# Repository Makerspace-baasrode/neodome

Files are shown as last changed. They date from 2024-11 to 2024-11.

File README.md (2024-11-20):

# Neodome
Neodome is geodesic dome made from PVC tube trusses lined with neopixel LED strips. Its first installation was in August 16th to 18th 2024 at [Fri3d Camp](https://fri3d.be/), a hacker camp in Belgium.

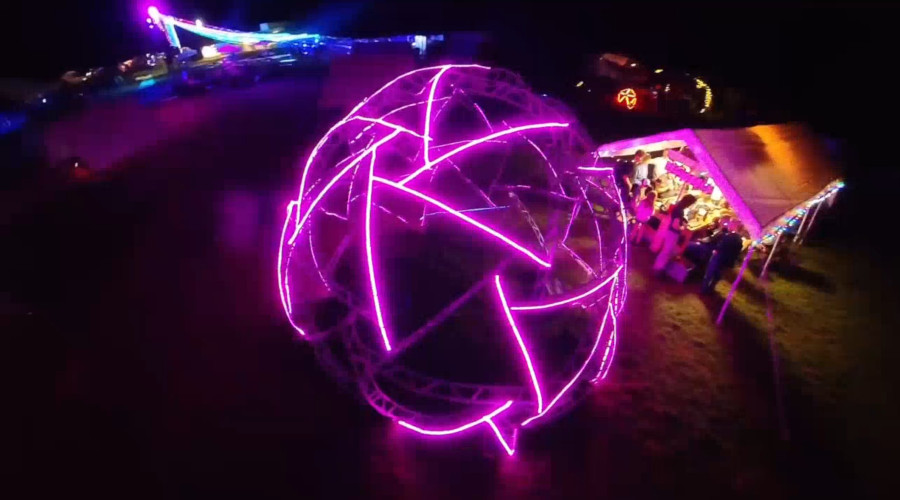
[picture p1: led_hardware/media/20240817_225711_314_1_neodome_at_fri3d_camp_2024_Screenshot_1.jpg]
Neodome at Fri3d Camp 2024


## Neo Dome? Neodome!
[Koen](https://github.com/kavers1) explains that the project is called "Neodome" for these reasons:
1. It features a *dome* with *neo*pixels.
2. It represents a *new* design of a geodesic dome, specifically for Koen.
3. The design, as far as he has been able to find, appears to be *unique*. The shape incorporates pentagons and hexagons, with triangles in between, a configuration that Koen has not yet come across on any other websites or in his searches. While he hasn't conducted an exhaustive search, he has already explored numerous resources. Hence, he chose the name **Neodome**.

## Folders
This project is divided in these folders:
- [dome_hardware](./dome_hardware/): The geodesic dome hardware (constructed with PVC electrical conduits).
- [led_hardware](./led_hardware/): The LED hardware (power supplies, addressable LED strips, power distribution and IRA nodes).
- [led_software](./led_software/): firmware running on the IRA nodes (WLED, WLED with NATS) and possibly other external software controlling the lighting.

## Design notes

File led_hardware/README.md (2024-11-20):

# Neodome lighting hardware and network infrastructure setup

Neodome uses 15 **IRA boards** that each control 5 addressable LED strips. The [IRA](https://github.com/phyx-be/IRA) is a printed circuit board with an ESP32 to control LEDs (or other lighting equipment). The PCB is designed for a 5 or 12V DC supply voltage and has outputs for WS2812-style adressable LEDs and optional DMX. Because of the size of neodome, 12V power is used.

An **IRA node** is an electrical juncion box housing an IRA PCB (to make it somewhat wheater proof). The node has a black/red wire pair for the 12V DC supply and 5 wire triplets with wheather proof connectors for connecting an LED strip. Every box is marked with the node number (926-930) on the front and back. An IRA node is mounted in the intersection of 6 trusses on the *neodome* and feeds the LED strips of 5 trusses. The LED strip of the 'missing' truss is fed by an adjacent IRA node.

By default IRA runs Micropython and NATS is used to transfer commands over wifi. For neodome the IRA boards are flashed with standard WLED firmware. Future plan is flashing WLED with the IRA_NATS usermod: https://github.com/kavers1/WLED/tree/NATS-IO

## Bill Of Materials
* LED strips: type, lengths?
* 15 IRA nodes
* 230V AC to 12V DC power supplies
* 12V DC distribution cables: lenght?
* Lots of WAGO connectors for connecting the power supplies to the distribution cables and the distribution cables to the IRA bnodes
* Wifi AP 

## Wifi
The Wifi AP is an Aruba AP-105 access point running OpenWRT. It is configured to run standalone on PoE without an ethernet uplink and supplies reserved IP-addresses to the IRA nodes.

## WLED on IRA

### Network Parameters

| IRA Node name | IP address | ESP wifi MAC |
|---|---|---|
| wled-Dome-Node-916 | 10.5.5.16  | C8:2B:96:8A:54:1C |
| wled-Dome-Node-917 | 10.5.5.17  | C8:2B:96:8B:15:98 |
| wled-Dome-Node-918 | 10.5.5.18  | C8:2B:96:8B:16:F4 |
| wled-Dome-Node-919 | 10.5.5.19  | C8:2B:96:8B:17:10 |
| wled-Dome-Node-920 | 10.5.5.20  | C8:2B:96:8B:17:64 |
| wled-Dome-Node-921 | 10.5.5.21  | C8:2B:96:8B:17:94 |
| wled-Dome-Node-922 | 10.5.5.22  | C8:2B:96:8B:16:D4 |
| wled-Dome-Node-923 | 10.5.5.23  | C8:2B:96:8B:16:C4 |
| wled-Dome-Node-924 | 10.5.5.24  | C8:2B:96:8B:16:D8 |
| wled-Dome-Node-925 | 10.5.5.25  | C8:2B:96:8B:15:88 |
| wled-Dome-Node-926 | 10.5.5.26  | C8:2B:96:8B:16:D0 |
| wled-Dome-Node-927 | 10.5.5.27  | C8:2B:96:8B:17:5C |
| wled-Dome-Node-928 | 10.5.5.28  | C8:2B:96:8B:15:94 |
| wled-Dome-Node-929 | 10.5.5.29  | C8:2B:96:8B:16:F8 |
| wled-Dome-Node-930 | 10.5.5.30  | C8:2B:96:8B:17:14 |

The DHCP configuration of the wifi access point has IP reservations mapping the MAC to the assigned IP address for every IRA node.

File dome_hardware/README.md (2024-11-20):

# Neodome
Neodome is a neopixel lined geodesic dome. This README covers the build of the geodesic dome.

First build of the neodome, banaan for scale

## Bill Of Materials
- PVC electrical conduit tubes
  - 20x big: diameter? length?
  - 100x? small: diameter? length?
- PVC glue
- 260 to 280 [Locking Pin](https://www.techniekwebshop.nl/gopart-borgpen-8-x-45mm-lp845gp-45-mm-7-mm.html)

## Tools
<!-- TO DO: add the needed tools for component build and assembly -->
- 8.5mm drill for Locking Pin holes

## Component build
Build the appropriate amount of every component.

| Component | Amount needed | STL file for 3D printing a model |
|---|---:|---|
| Penta truss | 40 | [model/penta_truss3_3D.stl] |
| Hexa truss | 20 | [model/hexa_truss3_3D.stl] |
| Penta ground truss | 5 | [model/penta_ground_truss3_3D.stl] |
| Hexa ground truss | 5 | [model/hexa_ground_truss3_3D.stl] |
| Ground truss | 5 | [model/hexa_ground_truss3_3D.stl] |

### Printing a 3D model
The [model](model/) folder contains STL files you can print with a 3D printer. If you first build the dome with the 3D printed pieces, you have a model as reference. If you use a scaling factor of 0.1, 1 m becomes 10 cm.

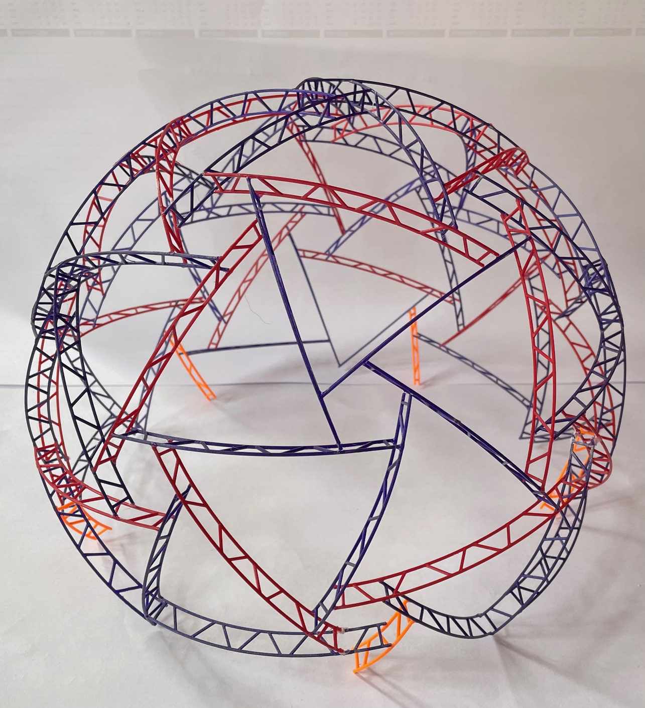
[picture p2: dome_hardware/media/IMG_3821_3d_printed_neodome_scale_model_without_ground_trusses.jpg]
A 3D printed scale model of neodome without the ground trusses


If you also print the *ground trusses*, your model will stand more stable:
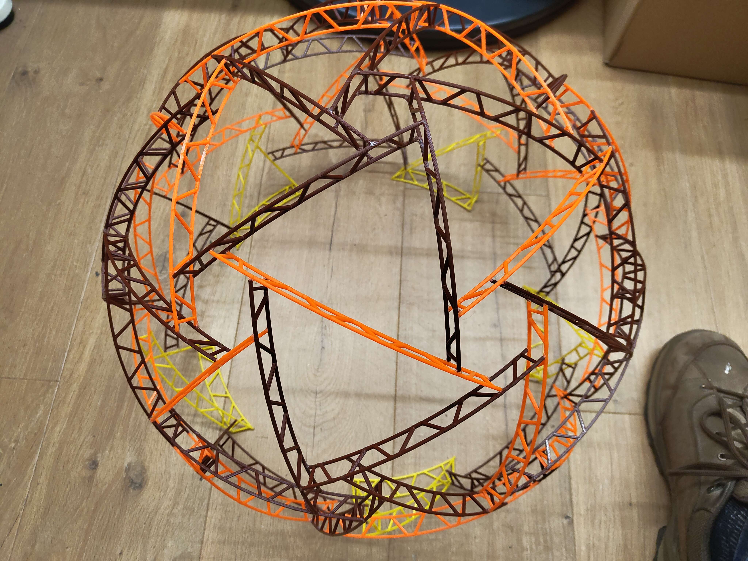
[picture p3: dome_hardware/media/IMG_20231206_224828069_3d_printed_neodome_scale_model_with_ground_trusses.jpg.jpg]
A 3D printed scale model of neodome with the ground trusses


### Tube lengths

- 500x Diagonals of ? length and ? diameter
- **To be further determined**

### Tube hole drilling

You can use a jig for drilling the holes at the correct spacing:
A simple but effective hole drilling jig

### Truss construction

You will need different diameters and lengths of PVC electrical conduit to build every component. Every truss component is a 2D construction consisting of 2 long tubes connected by short diagonals and 2 shorter connecting tubes at each end that accept another truss:

A completed truss
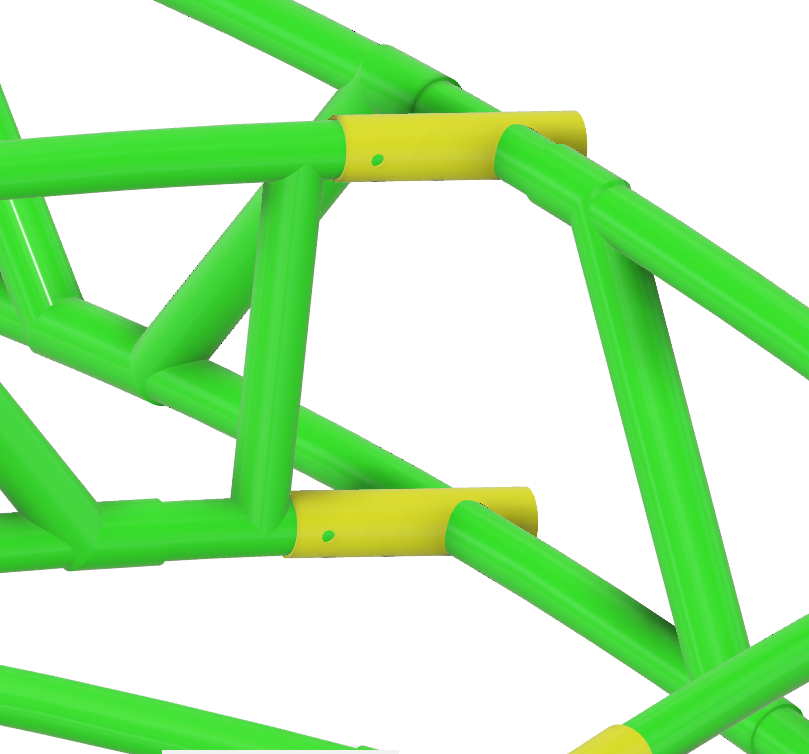
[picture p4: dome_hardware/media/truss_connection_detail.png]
3D generated detail of a truss connector (yellow)


| Component | Outer Diameter | Length | Amount |
|---|---|---|---|

## Component Assembly
Assemble the components is the correct steps. First building the top part.

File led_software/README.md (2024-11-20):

# WLED software

To keep it simple, and as a first step to light up the neodome, we use the default WLED firmware.

## WLED configuration files

To simplify the WLED configuration for 15 nodes, open the [WLED configuration template](wled_cfg_neodome_NNN.json) and find and replace NNN with the IRA Node number. Save the resulting file as wled_cfg_neodome_-`Node number`.json

## Flashing WLED firmware on IRA board

1.  Disconnect everything from the IRA board: no LED strips or 12V power!
2.  Push the BOOT button on the PCB while connecting the PCB with USB-C to your PC.
3.  Open the [WLED web installer](https://install.wled.me) in a chromium-based web browser.
4.  Select firmware version 0.14.3 build 2404040
> Note that we experienced serious lag and irresponsiveness running WLED firmware version 0.14.4! This was manifested in mostly timeouts and occasional high ping responses exceeding 1 second while normal responses should be around 10 milliseconds or less. 
5.  Click `Install` and select the appropriate serial port and Connect.
6.  Click `INSTALL WLED` and `INSTALL`. This will take about 2 minutes.
7.  Click `NEXT` when installation is complete, select the `Makerspace-Baasrode` wifi network and enter the Password to connect.
8.  Click `VISIT DEVICE` to open the WLED web interface

## WLED on IRA configuration

1.  Navigate to the WLED web interface of the neodome IRA board
2.  Config > Security & Updates
3.  Choose file under `Restore presets`, select `wled_presets_neodome.json` and click `Upload`. You should get a green `File Uploaded!` popup.
4.  Choose file under `Restore configuration`, select wled_cfg_neodome_`Node number`.json and click `Upload`. You should get a green `Configuration restores succesfull. Rebooting!` popup.

## WLED on IRA manual configuration via GUI
        
- Wifi setup
  - Network name: `Makerspace-Baasrode`
  - Network password: `password`
  - mDNS address: `wled-930`
  - AP SSID: `WLED-AP-930`
- LED Preferences
  - Maximum Current: `2000`
  - LED voltage: `12V 30mA`
  - LED outputs 1 Length: `45`
  - LED outputs 1 GPIO: `4`
  - LED outputs 1 Color Order: `BRG`
  - LED outputs 2 Length: `45`
  - LED outputs 2 GPIO: `12`
  - LED outputs 3 Length: `45`
  - LED outputs 3 GPIO: `14`
  - LED outputs 4 Length: `45`
  - LED outputs 4 GPIO: `25`
  - LED outputs 5 Length: `45`
  - LED outputs 5 GPIO: `27`
  - Apply preset at boot: `1`
 - User Interface
   - Server description: `Dome-Node-930`
   - Preset: `pink` / `solid`, preset `1`
        
Url for downloading JSON config: http://4.3.2.1/json/cfg when connected to the WLED AP.

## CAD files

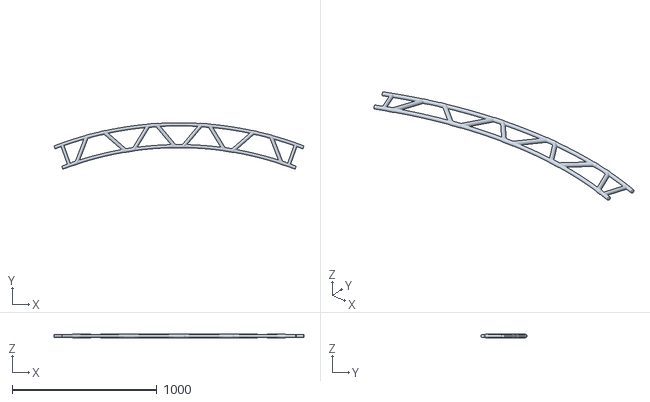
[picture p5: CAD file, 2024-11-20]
dome_hardware/model/penta_truss3_3D.stl
1726.0 x 320.4 x 25.0

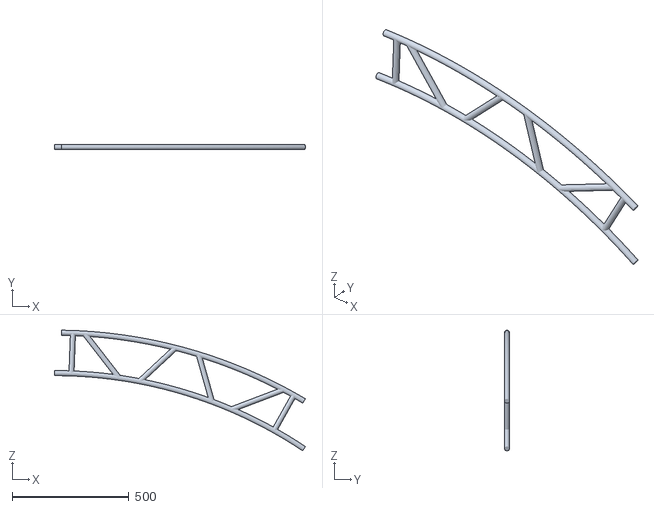
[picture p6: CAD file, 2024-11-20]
dome_hardware/model/ground_truss_3D.stl
1077.0 x 22.0 x 517.8

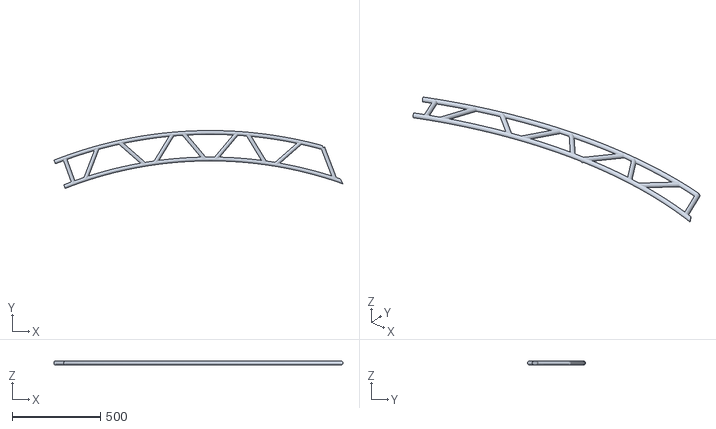
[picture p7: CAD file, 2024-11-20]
dome_hardware/model/penta_ground_truss3_3D.stl
1635.1 x 327.7 x 22.0

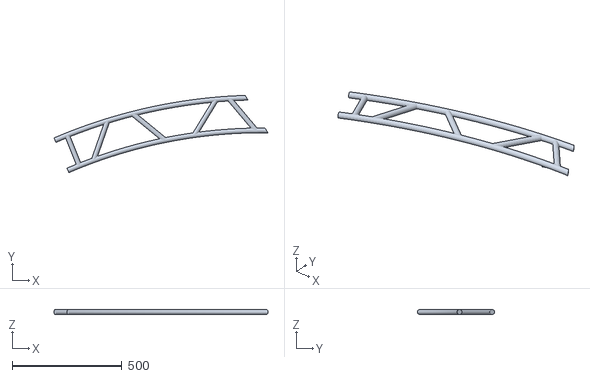
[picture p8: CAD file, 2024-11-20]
dome_hardware/model/hexa_ground_truss3_3D.stl
976.2 x 352.4 x 22.0

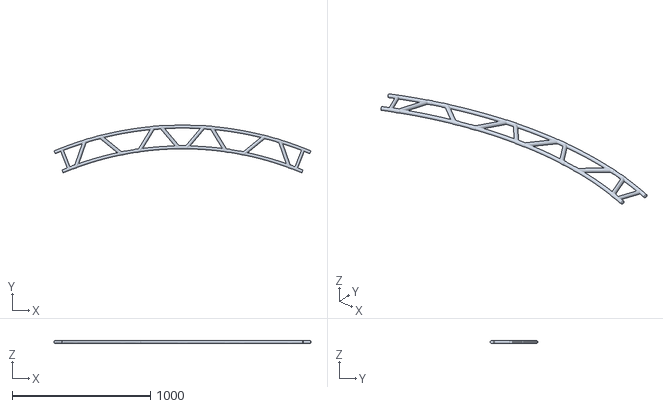
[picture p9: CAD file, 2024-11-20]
dome_hardware/model/hexa_truss3_3D.stl
1862.1 x 345.6 x 25.0

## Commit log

2024-11-20 add dome_hardware README, media and STL files for scale model
    [ground_truss_3D.stl, hexa_ground_truss3_3D.stl, hexa_truss3_3D.stl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]
2024-11-20 LED hardware and software
